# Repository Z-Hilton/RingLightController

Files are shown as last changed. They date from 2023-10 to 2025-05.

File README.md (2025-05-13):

# Ringlight Controller README

Welcome to the Ringlight Controller documentation! This guide will help you understand how the ringlight controller board works, even if you're not a programmer or electrical engineer. We'll break down the components, their functions, and the overall operation in a simple and organized manner.

## Table of Contents

1. **Introduction**
2. **Components**
3. **Power Supply**
4. **ESP32 Microcontroller**
5. **RGB LED Strip**
6. **Operation**

## 1. Introduction

The Ringlight Controller is a device designed to control a ringlight, which is often used for photography and video lighting. This controller is built around an ESP32 microcontroller and is capable of turning on and off the ringlight's LEDs in sync with a shutter signal.

###### Design Choices
This project from the start was meant to be done
* as fast as possible
* as simple as possible
* as robust as possible (i.e. can be easily improved upon later)

This means that there are potentially lots of optimizations that could be made, as I chose parts I am most familiar with and think that most people will find easy to use. Below I will provide a brief description of how the board works, piece by piece.

## 2. Components

#### 2.1 Mosfets (6)

- These are electronic switches that control the flow of electrical current. There are six of them on the board (circled in red below)
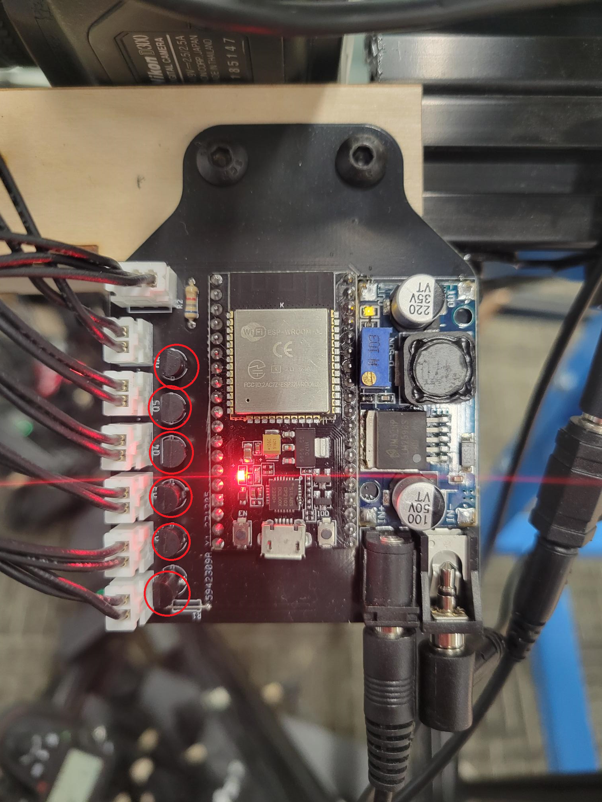
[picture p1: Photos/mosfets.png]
Mosfets


#### 2.2 Buck Converter

- This component steps down the input voltage from 24V to 5V. It provides power to both the ESP32 and the 3-pin RGB LED strip (not the 2-pin white leds, those need the full 24V). I refer to the entire blue PCB as one component - the buck converter. These can be bought for under a dollar at the BYU ECE shop (Northeast corner of the 4th floor of the Clyde building) or online. You can tune the output voltage using a small flat screwdriver. I have tuned them to output 5V, which can be checked using a handheld voltmeter.
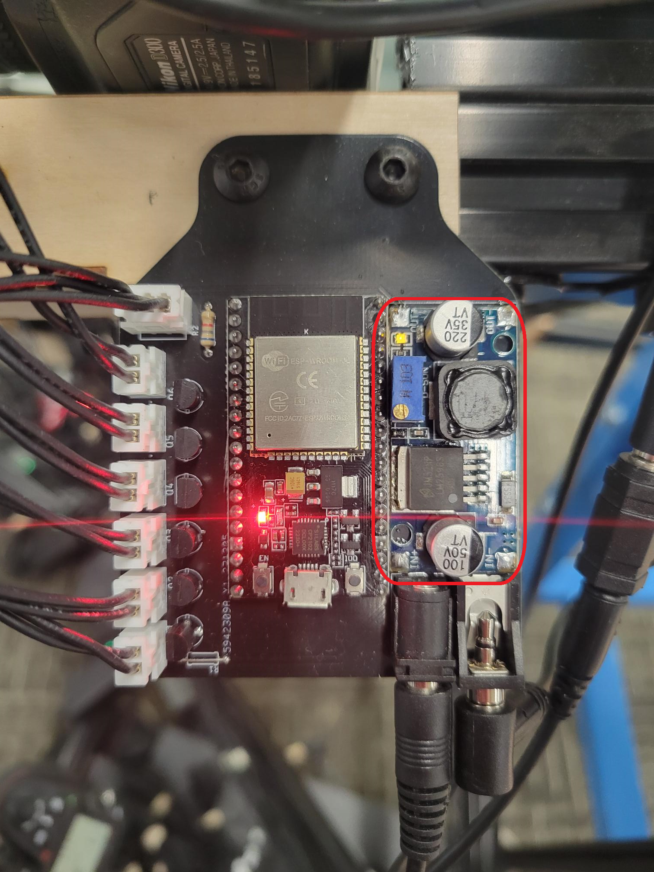
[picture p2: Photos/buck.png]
Buck


#### 2.3 ESP32

The ESP32 is the heart of the controller. It performs the following tasks:

- **Detect Shutter Signal:** The ESP32 listens for a shutter signal coming from a 3.5mm headphone jack on the board. This signal tells the controller when to turn on the ringlight.

- **Control Mosfets:** When the shutter signal is detected, the ESP32 sends a signal to the Mosfets to turn them on. This allows the 24V power to flow to the white LED banks.

- **Control RGB LEDs** The ESP32 uses just one pin to control all 24 RGB LEDs of the ringlight. There are a couple of libraries you can use in the Arduino IDE to control them, with NEOpixel being arguably the easiest.
- For its dimensions and pinout, go [here.](https://docs.ai-thinker.com/en/esp32/boards/nodemcu_32s) Don't worry about anything else on that page, we program it using the Arduino IDE, which is much simpler than the process described by the manufacturer.
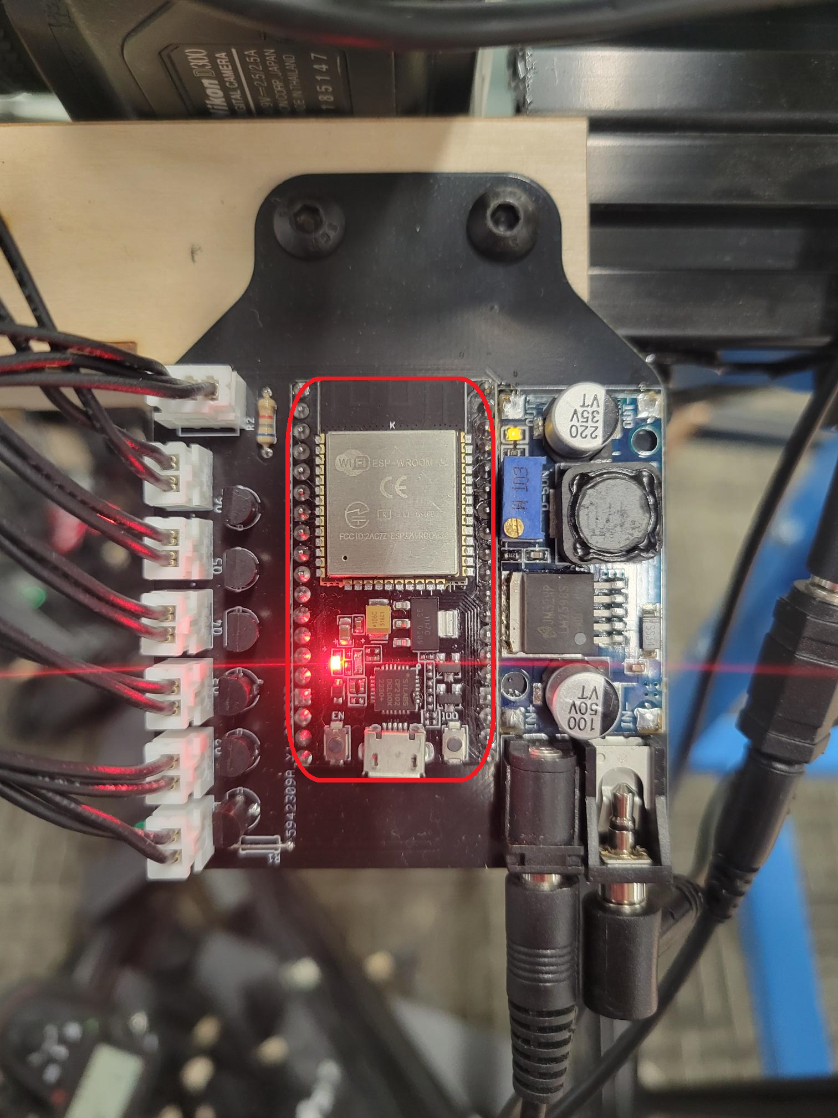
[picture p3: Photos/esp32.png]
esp


#### 2.4 JST connectors (6, 2-pins)

- Each of these go to a bank of 6 LEDs on the ringlight board that is mounted to a camera.
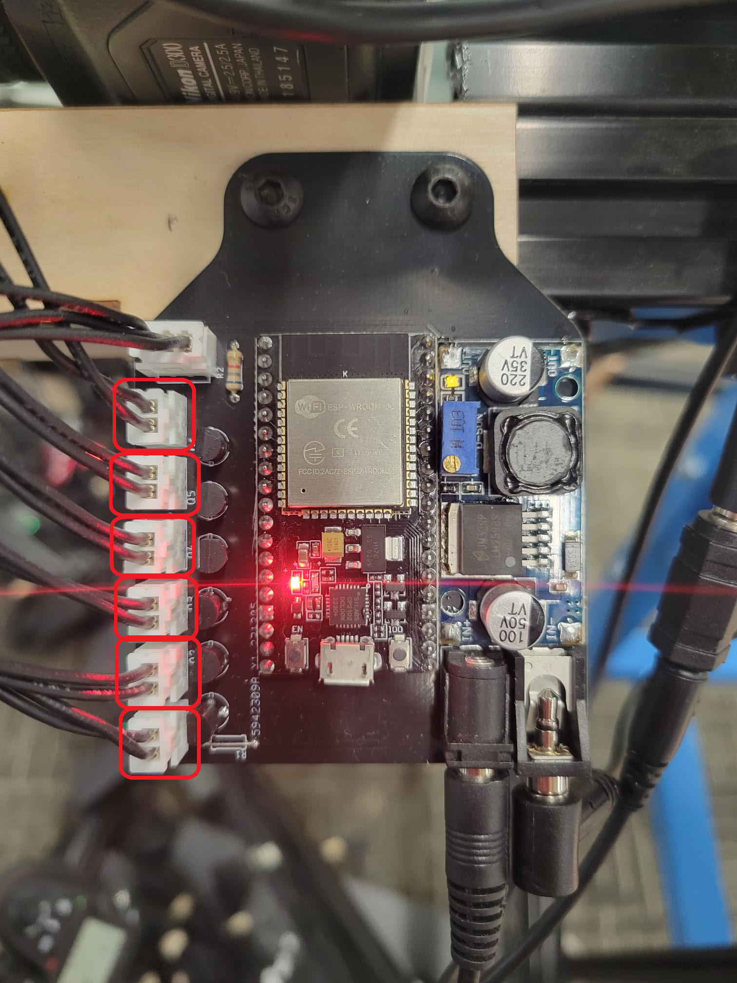
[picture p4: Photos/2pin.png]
2pin

  
#### 2.5 JST connector (1, 3-pin)

- The three pins are ground, data, and power (5V). They go to the individually addressable RGB LEDs on the ringlight.
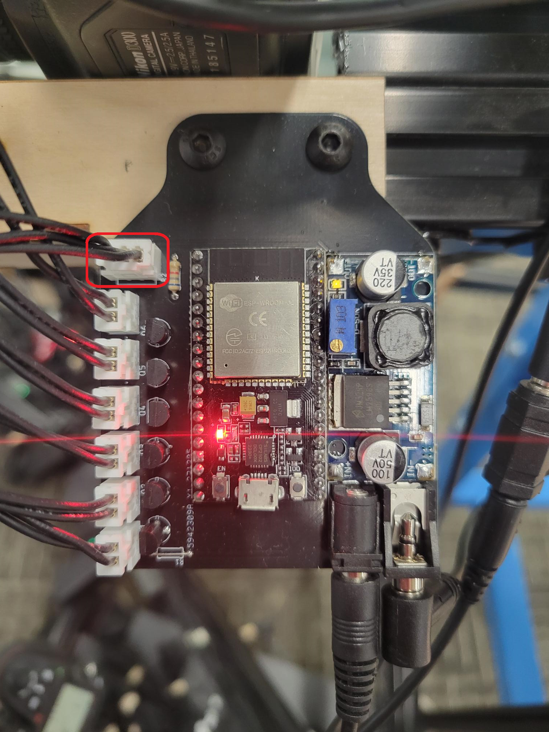
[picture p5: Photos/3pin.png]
3pin

  
#### 2.6 3.5mm Jack

- Gets the signal from the camera
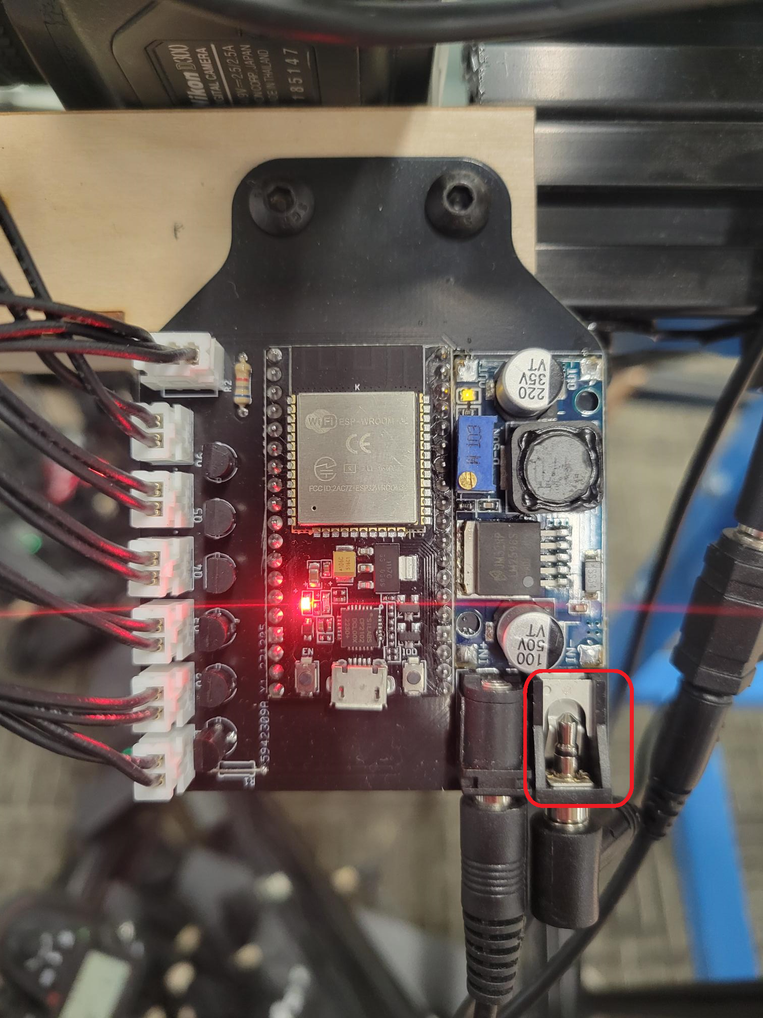
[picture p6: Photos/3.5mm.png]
3.5mm


#### 2.7 Barrel Jack

- Gets power to the buck converter and ESP32
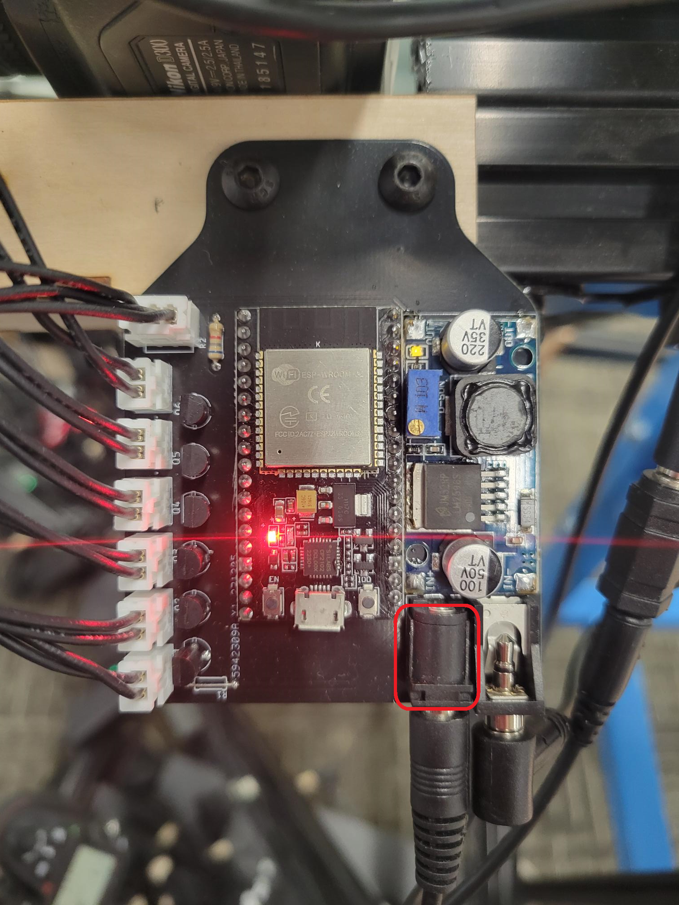
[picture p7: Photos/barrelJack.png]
barrelJack


## 3. Supplying Power

The board expects an input of 24 Volts throught a **_center-positive_** DC barrel jack. You can check to see if your power source is center-positive by placing the red probe of a volt meter in the center of the plug and the black probe on the sleeve. If the number is positive you are all good. (This is important as there is no standard and center-negative is quite common too). The power supplies we are using for the photogrammetry rig are center-positive, so if you are a Makerspace employee reading this, no need to worry about this.
Again, here's how the power flows through the board:
- The 24V power goes into the board.
- A Buck Converter steps down the voltage to 5V.
- The 5V output powers both the ESP32 and the RGB LED strip.

## 6. Operation

Here's how the Ringlight Controller operates in simple terms:

1. **Power Supply:** Connect a 24V power source to the board.

2. **Shutter Signal:** Connect a device (e.g., a camera) to the 3.5mm headphone jack on the board. When you trigger the camera's shutter, it sends a signal to the board.

3. **ESP32 Activation:** The ESP32 detects the shutter signal and activates the Mosfets.

4. **Mosfet Activation:** The Mosfets turn on, allowing the 24V power to flow to the LED banks in the ringlight.

5. **Ringlight Illumination:** The ringlight's LEDs turn on, and we have lighting.

# WARNING!!!

- NEVER PLUG ANYTHING INTO THE MICROUSB IF THE BOARD IS BEING POWERED BY THE 24V BARREL JACK. IT WILL DESTROY THE ESP32 AND MAYBE THE COMPUTER PORT
- If/When you reprogram the board, make 100% sure that the 24V is unplugged. The board will power up from just the usb, but the ringlights won't light up, and that is fine. 

That's it! You should now understand each part of how the Ringlight Controller works.

## Comments on the code
- testLights.ino is a simple working version of the code that simply flashes the lights when it detects the shutter has opened. 
- RCP (which stands for Ringlight Control Protocol) is an implementation of a way to wirelessly change the settings (ie flash duration, flash color, etc.) of each of the boards without having to plug in to each board individually, as that proves VERY tedious. esp32's were chosen because of their WiFi capabilities. The sender code runs on a separate esp32 outside the rig, and the receiver code is meant to be ran on all the boards on the rig. Currently, none of the esp32s in the rig have this code on them because the RCP code was/is still under development.

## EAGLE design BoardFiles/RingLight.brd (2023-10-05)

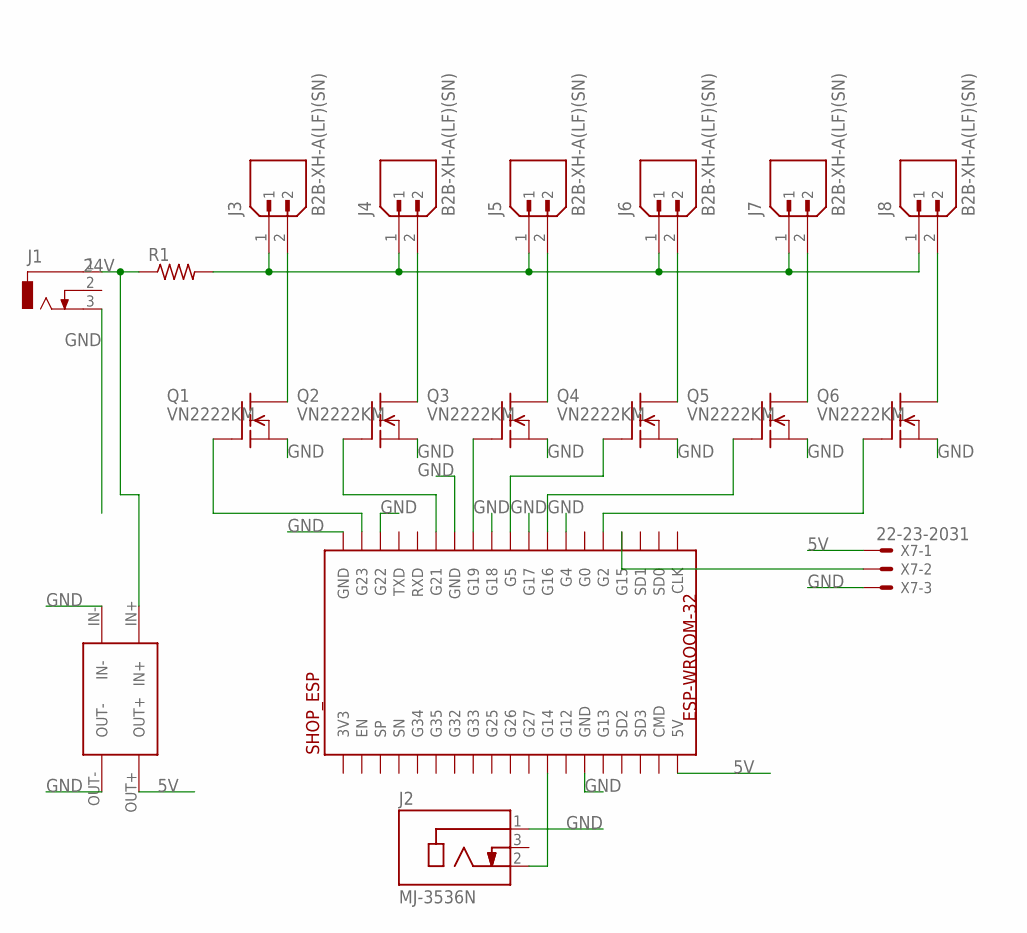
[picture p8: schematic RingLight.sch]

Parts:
J1: DCJ0303
J2: MJ-3536N; CUI_MJ-3536N
J3, J4, J5, J6, J7, J8: B2B-XH-A(LF)(SN); JST_B2B-XH-A(LF)(SN)
Q1, Q2, Q3, Q4, Q5, Q6: VN2222KM; TO237
R1: R-US_0204/7; 0204/7
U$2: BUCK-CONVERTER; LM2596DC-DC
U$4: SHOP_ESP; ESP32-WROOM-32
X7: 22-23-2031

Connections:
3V3: U$4.P$19 (3V3)
5V: U$2.OUT+, U$4.P$1 (5V), X7.1
24V: J1.1, R1.1, U$2.IN+
CMD: U$4.P$2 (CMD)
GND: J1.3, J2.1, Q1.3 (S), Q2.3 (S), Q3.3 (S), Q4.3 (S), Q5.3 (S), Q6.3 (S), U$2.IN-, U$2.OUT-, U$4.P$6 (GND), U$4.P$26 (G4), U$4.P$28 (G17), U$4.P$30 (G18), U$4.P$32 (GND), U$4.P$36 (G22), U$4.P$38 (GND), X7.3
IN: J3.1, J4.1, J5.1, J6.1, J7.1, J8.1, R1.2
unnamed: J3.2, Q1.1 (D)
unnamed: J4.2, Q2.1 (D)
unnamed: J5.2, Q3.1 (D)
unnamed: J6.2, Q4.1 (D)
unnamed: J7.2, Q5.1 (D)
unnamed: Q1.2 (G), U$4.P$37 (G23)
unnamed: U$4.P$23 (G15), X7.2
unnamed: Q2.2 (G), U$4.P$33 (G21)
unnamed: Q3.2 (G), U$4.P$31 (G19)
unnamed: Q4.2 (G), U$4.P$29 (G5)
unnamed: Q5.2 (G), U$4.P$27 (G16)
unnamed: Q6.2 (G), U$4.P$24 (G2)
unnamed: J2.2, U$4.P$8 (G14)
unnamed: J8.2, Q6.1 (D)

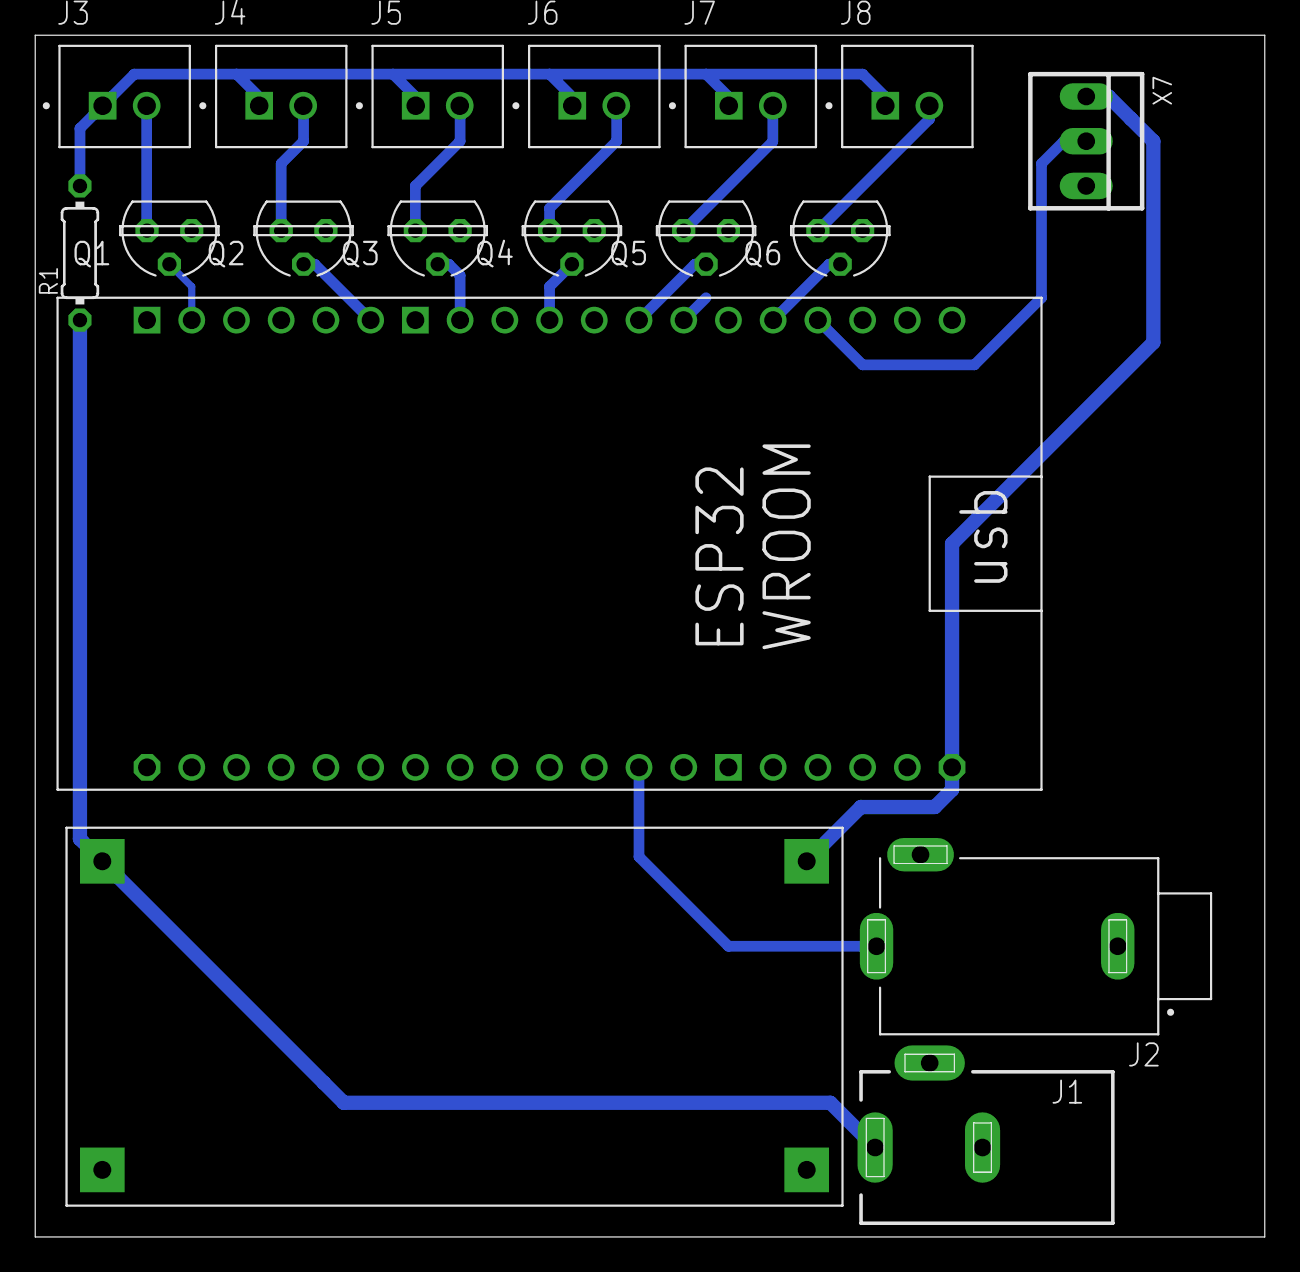
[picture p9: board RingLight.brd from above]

Board: 2 copper layers, 69.8 x 68.2 mm, 18 parts (0 on the bottom side), 18 nets.

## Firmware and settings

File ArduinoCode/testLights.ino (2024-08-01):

#include <FastLED.h>

#define RGB_LED_PIN 15      // Pin connected to the Data Input of WS2812B
#define NUM_LEDS 24     // Number of WS2812B LEDs in the strip
#define LED_TYPE    WS2812B  // Adjust the LED type accordingly
#define BRIGHTNESS 255  // Set the brightness (0-255)

#define SHUTTER_PIN 34  //Pin connected to the shutter signal of the cameras via 3.5mm jack

CRGB leds[NUM_LEDS];

void setup() {
  // setup code here, to run once:
  pinMode(18, OUTPUT); // set each bank of 6 White Leds as outputs
  pinMode(19, OUTPUT);
  pinMode(21, OUTPUT);
  pinMode(22, OUTPUT);
  pinMode(23, OUTPUT);
  pinMode(25, OUTPUT);  
  digitalWrite(18, LOW);
  digitalWrite(19, LOW);
  digitalWrite(21, LOW);
  digitalWrite(22, LOW);
  digitalWrite(23, LOW);
  digitalWrite(25, LOW);                                                                                                                                                                                                                                                                               
  // set the shutterPin as a normally-high input
  pinMode(SHUTTER_PIN, INPUT_PULLUP); 
  // To control rgb leds
  FastLED.addLeds<LED_TYPE, RGB_LED_PIN, GRB>(leds, NUM_LEDS);
  pinMode(SHUTTER_PIN, INPUT_PULLUP);
  FastLED.clear();  // Turn off all LEDs initially



}

void loop() {
  //main code here, to run repeatedly:
  // if the shutter signal drops, flash on and off
  if (digitalRead(SHUTTER_PIN) != 0) { 
    digitalWrite(18, HIGH);
    digitalWrite(19, HIGH);
    digitalWrite(21, HIGH);
    digitalWrite(22, HIGH);
    digitalWrite(23, HIGH);
    digitalWrite(25, HIGH); 
    delayMicroseconds(10); 
    digitalWrite(18, LOW);
    digitalWrite(19, LOW);
    digitalWrite(21, LOW);
    digitalWrite(22, LOW);
    digitalWrite(23, LOW);
    digitalWrite(25, LOW); 
    delay(10);
  } else {
    turnOnRed();
    digitalWrite(18, HIGH);
    digitalWrite(19, HIGH);
    digitalWrite(21, HIGH);
    digitalWrite(22, HIGH);
    digitalWrite(23, HIGH);
    digitalWrite(25, HIGH); 
    delay(2); 

    FastLED.clear();
    FastLED.show();
    digitalWrite(18, LOW);
    digitalWrite(19, LOW);
    digitalWrite(21, LOW);
    digitalWrite(22, LOW);
    digitalWrite(23, LOW);
    digitalWrite(25, LOW); 
    delay(10);    
  }

}

void turnOnWhite() {
  for (int i = 0; i < NUM_LEDS; i++) {
    leds[i] = CRGB::White;
  }
  FastLED.show();
}
void turnOnRed() {
  for (int i = 0; i < NUM_LEDS; i++) {
    leds[i] = CRGB::Red;
  }
  FastLED.show();
}

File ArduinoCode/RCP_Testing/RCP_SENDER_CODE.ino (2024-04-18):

// Controller Code
#include <esp_now.h>
#include <WiFi.h>
#define RESEND_COUNT 3
#define A1 {0x24, 0x0A, 0xC4, 0x12, 0x34, 0x56}
#define A2 {0x24, 0x0A, 0xC4, 0x78, 0x9A, 0xBC}
#define A3 {0x24, 0x0A, 0xC4, 0xDE, 0xF0, 0x12}
#define A4 {0x24, 0x0A, 0xC4, 0x34, 0x56, 0x78}
#define A5 {0x24, 0x0A, 0xC4, 0x9A, 0xBC, 0xDE}
#define A6 {0x24, 0x0A, 0xC4, 0xF0, 0x12, 0x34}
#define B1 {0x24, 0x0A, 0xC4, 0x56, 0x78, 0x9A}
#define B2 {0x24, 0x0A, 0xC4, 0xBC, 0xDE, 0xF0}
#define B3 {0x24, 0x0A, 0xC4, 0x12, 0x34, 0x56}
#define B4 {0x24, 0x0A, 0xC4, 0x78, 0x9A, 0xBC}
#define B5 {0x24, 0x0A, 0xC4, 0xDE, 0xF0, 0x12}
#define B6 {0x24, 0x0A, 0xC4, 0x34, 0x56, 0x78}
#define C1 {0x24, 0x0A, 0xC4, 0x9A, 0xBC, 0xDE}
#define C2 {0x24, 0x0A, 0xC4, 0xF0, 0x12, 0x34}
#define C3 {0x24, 0x0A, 0xC4, 0x56, 0x78, 0x9A}
#define C4 {0x24, 0x0A, 0xC4, 0xBC, 0xDE, 0xF0}
#define C5 {0x24, 0x0A, 0xC4, 0x12, 0x34, 0x56}
#define C6 {0x24, 0x0A, 0xC4, 0x78, 0x9A, 0xBC}
#define D1 {0x24, 0x0A, 0xC4, 0xDE, 0xF0, 0x12}
#define D2 {0x24, 0x0A, 0xC4, 0x34, 0x56, 0x78}
#define D3 {0x24, 0x0A, 0xC4, 0x9A, 0xBC, 0xDE}
#define D4 {0x24, 0x0A, 0xC4, 0xF0, 0x12, 0x34}
#define D5 {0x24, 0x0A, 0xC4, 0x56, 0x78, 0x9A}
#define D6 {0x24, 0x0A, 0xC4, 0xBC, 0xDE, 0xF0}
#define E1 {0x24, 0x0A, 0xC4, 0x12, 0x34, 0x56}
#define E2 {0x24, 0x0A, 0xC4, 0x78, 0x9A, 0xBC}
#define E3 {0x24, 0x0A, 0xC4, 0xDE, 0xF0, 0x12}
#define E4 {0x24, 0x0A, 0xC4, 0x34, 0x56, 0x78}
#define E5 {0x24, 0x0A, 0xC4, 0x9A, 0xBC, 0xDE}
#define F1 {0x24, 0x0A, 0xC4, 0xF0, 0x12, 0x34}
#define F2 {0x24, 0x0A, 0xC4, 0x56, 0x78, 0x9A}
#define F3 {0x24, 0x0A, 0xC4, 0xBC, 0xDE, 0xF0}
#define F4 {0x24, 0x0A, 0xC4, 0x12, 0x34, 0x56}
#define F5 {0x24, 0x0A, 0xC4, 0x78, 0x9A, 0xBC}
#define F6 {0x24, 0x0A, 0xC4, 0xDE, 0xF0, 0x12}

uint8_t broadcastAddr[] = {0xFF, 0xFF,0xFF,0xFF,0xFF,0xFF};
uint8_t test1Addr[] =     {0x1};
uint8_t test2Addr[] =     {0x1};

// Ringlight MAC Addresses
uint8_t ringLightAddresses[][6] = {
  {0x30, 0xAE, 0xA4, 0x45, 0x6F, 0x9B}, // Ringlight 1
  {0x3C, 0x61, 0x05, 0x1A, 0x0B, 0xB5}, // Ringlight 2
  //A1, A2, A3, A4, A5, A6,   Add more ringlight addresses here
  //B1, B2, B3, B4, B5, B6,
  //C1, C2, C3, C4, C5, C6,
  //D1, D2, D3, D4, D5, D6,
  //E1, E2, E3, E4, E5,
  //F1, F2, F3, F4, F5, F6
};

// Packet Structure
typedef struct {
  uint8_t addresses[20][6]; // Max 20 addresses per packet 
  uint8_t colors[20][3];    // RGB color values
  uint8_t count;            // Number of devices in this packet
} RCPData;

RCPData data;

void sendRCPPacket() { 
  for (uint8_t i = 0; i < RESEND_COUNT; i++) {
    esp_now_send(broadcastAddr, (uint8_t*)&data, sizeof(data)); // broadcastAddr instead of NULL; NULL sends to all registered peers, of which we have none
    delay(10); // Add a small delay between resends
  }
}

void loadRCPPacket(uint8_t* macAddrToAdd, uint8_t r, uint8_t g, uint8_t b) {
  // Add the MAC address and color to the data struct
  for(uint8_t i = 0; i < 6; i++) {// ... (mac addresses are 6 bytes long)
    data.addresses[data.count][i] = macAddrToAdd[i];
  }
  data.colors[data.count][0] = r;
  data.colors[data.count][1] = g;
  data.colors[data.count][2] = b;
  data.count++;

  // If we've reached 20 devices, send the packet
  if (data.count == 20) {
    sendRCPPacket();
    data.count = 0; // Reset count
  }
}

void setColor(uint8_t r, uint8_t g, uint8_t b) {// sets all ringlights the same color.
  // Iterate through all 40 ringlights and call loadRCPPacket
  // Example:
  for(uint8_t i = 0; i < 40; i++) {
    loadRCPPacket(ringLightAddresses[i], r, g, b);  
  }
}

void setup() {
  Serial.begin(115200);
  WiFi.mode(WIFI_STA);
  if (esp_now_init() != ESP_OK) {
    Serial.println("Error initializing ESP-NOW");
    return;
  }
  setColor(123,241,111);
}

void loop() {
  // Handle any other logic here
}

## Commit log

2023-10-05 v2 beta board
    [RingLight.brd, RingLight.sch]
2023-10-05 moved to folder
    [RingLight.sch]
2023-10-05 Update and rename testLights.ino to ArduinoCode/testLights.ino
2024-08-01 Updated testLights.ino
    Updated the pins to work with the new NodeMCU esp32 and corresponding PCB. The new code has the lights always dimly on to help the cameras focus. The main flash is the same as before.
2024-12-03 Added esp32 documentation
    This is the datasheet that has the pinout for the specific esp32's I used in the ringlights.
2025-01-04 Update README.md
    Added highlighted images, changed description of buck converter, linked to the pinout of the esp32
